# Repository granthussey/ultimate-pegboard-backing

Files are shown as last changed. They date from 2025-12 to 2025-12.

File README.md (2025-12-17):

# Pegboard Backing System

Modular pegboard backings with smart beveling and configurable peg placement patterns. Designed for 1" x 1" pegboards with 1/4" holes.

## Quick Start

**Just want to print?** Grab an STL from the `stl/` folder:
- `backing_2x1.stl` - 2-wide, 1-tall, corner pegs only
- `backing_2x2_grid.stl` - 2x2 with full grid of pegs
- `backing_3x2_maxhook.stl` - 3x2 with maximum hooks for heavy items

**Want to customize?** Use the OpenSCAD files in `scad/` with `pegboard_library.scad`.

## Print Settings

- **Layer height:** 0.2mm recommended
- **Infill:** 20-30% for light items, 50%+ for heavy items
- **Supports:** None needed
- **Orientation:** Print flat (pegs pointing up)

## Backing Variants

| Suffix | Pattern | Best For |
|---|---|---|
| (none) | Corner pegs only | Light items |
| `_grid` | All pegs, corner hooks | Medium items |
| `_maxhook` | All pegs, all back hooks | Heavy items |
| `_support` | Corners + middle hook | Medium-light items |
| `_lite` | Corner pegs, center cutout | Light items, fast printing |
| `_grid_lite` | Grid + center cutout | Medium items, fast printing |
| `_maxhook_lite` | Maxhook + center cutout | Heavy items, fast printing |
| `_support_lite` | Support + center cutout | Medium-light items, fast printing |

### Lite Variants
The `_lite` variants have a rectangular cutout in the center, reducing material by ~40-50% and printing ~40-50% faster. A 6mm frame around the edges preserves structural integrity at the peg locations.

**Important:** For lite variants, pegs are only placed on the outer frame where material exists. Grid and maxhook patterns become perimeter patterns (no interior pegs since there's no backing material to support them).

Available lite versions:
- `backing_*_lite.stl` - Corner pegs only, lightweight
- `backing_*_grid_lite.stl` - Perimeter pegs, corner hooks, lightweight
- `backing_*_maxhook_lite.stl` - Perimeter pegs, all back hooks, lightweight
- `backing_*_support_lite.stl` - Corner pegs + middle hook, lightweight (3x1, 3x2 only)

### Grid vs Maxhook Equivalence

For **1-column backings** (1x2, 1x3), the `_grid` and `_maxhook` variants are **identical**. This is because the back row only has 2 peg positions (both corners), so "all back hooks" and "corner hooks" produce the same result. Use `_grid` for these sizes.

## Dimensions

| Grid | Size (mm) | Size (inches) |
|---|---|---|
| 1x1 | 31.75 x 31.75 | 1.25" x 1.25" |
| 2x1 | 57.15 x 31.75 | 2.25" x 1.25" |
| 3x1 | 82.55 x 31.75 | 3.25" x 1.25" |
| 2x2 | 57.15 x 57.15 | 2.25" x 2.25" |
| 3x2 | 82.55 x 57.15 | 3.25" x 2.25" |

## Customization

Create your own backing sizes using OpenSCAD:

```openscad
include <pegboard_library.scad>

$fn = 64;
cols = 3;  // Width in tiles
rows = 2;  // Height in tiles

// Choose your pattern:
pegboard_backing(cols, rows, "corners");           // Standard
pegboard_backing(cols, rows, "grid");              // Maxhook (all hooks)
pegboard_backing(cols, rows, "grid_corner_hooks"); // Grid (corner hooks)
pegboard_backing(cols, rows, "perimeter");         // Edge pegs

// Or use lite variants for faster printing:
pegboard_backing_lite(cols, rows, "corners");           // Standard lite
pegboard_backing_lite(cols, rows, "grid");              // Maxhook lite
pegboard_backing_lite(cols, rows, "grid_corner_hooks"); // Grid lite
```

### Adding Custom Geometry

```openscad
include <pegboard_library.scad>

$fn = 64;
cols = 2;
rows = 1;

pegboard_backing(cols, rows, "corners");

// Add your custom geometry on top
w = backing_width(cols);
h = backing_height(rows);

translate([w/2, h/2, BACKING_THICKNESS])
    your_custom_holder();
```

### Utility Functions

```openscad
backing_width(cols)    // Total width accounting for shared pegs
backing_height(rows)   // Total height accounting for shared pegs
peg_x(i, cols)         // X position for peg at column i
peg_y(j, rows)         // Y position for peg at row j
```

## Technical Details

### Core Parameters

| Parameter | Value | Description |
|---|---|---|
| `TILE_SIZE` | 31.75mm (1.25") | Single tile dimension |
| `PEG_DIAMETER` | 5.5mm | Peg diameter |
| `PEG_SPACING` | 25.4mm (1") | Pegboard hole spacing |
| `BACKING_THICKNESS` | 4mm | Backing plate thickness |

### Why PEG_SPACING = 25.4mm

Standard pegboards have holes spaced exactly **1 inch (25.4mm)** apart, center-to-center. Multi-tile backings use this spacing:

```
width = TILE_SIZE + (cols - 1) × PEG_SPACING
      = 31.75 + (cols - 1) × 25.4
```

This is why a 2x1 backing is 57.15mm wide, not 63.5mm.

### Interference-Fit Peg Spacing

The pegs are intentionally placed at `EDGE_OFFSET` (2.75mm) from the plate edges, **not** at the exact pegboard hole spacing. This creates a critical **interference fit**:

| Backing | Peg Spacing | Hole Spacing | Difference |
|---|---|---|---|
| 1x1 | 26.25mm | 25.4mm | +0.85mm |

**Why this matters:** The 0.85mm spread creates outward pressure when the pegs are inserted into the pegboard holes. This pressure makes the backing grip the holes securely instead of falling out.

If pegs were placed at exactly 25.4mm spacing, they would drop straight into the holes with no grip - the backing would be "too loose" and fall out easily.

**Technical details:**
- Corner pegs: Always at `EDGE_OFFSET` from plate edges (interference fit)
- Edge pegs (perimeter/grid): Corners use interference fit, intermediate positions use `peg_x()`/`peg_y()` for proper alignment
- Interior pegs (grid patterns): Use exact `peg_x()`/`peg_y()` spacing

## File Organization

```
pegboard_backing/
├── README.md              # This file
├── pegboard_library.scad  # Core library for customization
├── stl/                   # Ready-to-print STL files
│   ├── backing_*.stl
│   └── ...
└── scad/                  # OpenSCAD source files
    ├── backing_*.scad
    └── ...
```

## License

This work is licensed under [CC BY 4.0](https://creativecommons.org/licenses/by/4.0/). You are free to share and adapt, with attribution.

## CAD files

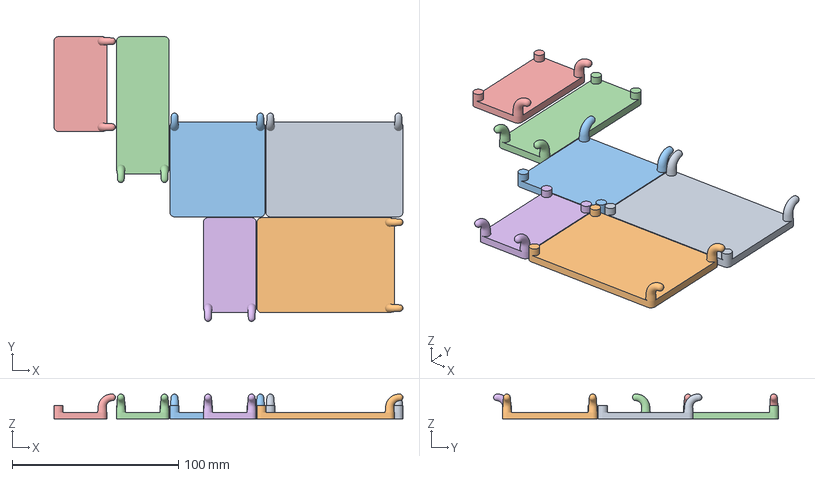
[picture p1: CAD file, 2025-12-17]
swatch.3mf
209.9 x 171.3 x 15.0 mm
backing_3x2_base
backing_2x3_base
backing_2x2_base
backing_1x3_base
backing_2x1_base
backing_1x2_base

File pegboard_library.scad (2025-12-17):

// ============================================================================
// PEGBOARD LIBRARY - Tiled Backing System with Smart Beveling
// ============================================================================
// For 1" x 1" pegboards with 1/4" holes
// Supports 1D and 2D tiling with adaptive peg placement
// ============================================================================
//
// QUICK REFERENCE - Peg Patterns for pegboard_backing(cols, rows, pattern):
//   "corners"          - 4 pegs at corners only (default)
//   "perimeter"        - Pegs around all edges at tile boundaries
//   "grid"             - All pegs, back row ALL hooks (_maxhook)
//   "grid_corner_hooks"- All pegs, only corner hooks (_grid)
//   "none"             - No pegs (backing plate only)
//
// IMPORTANT: Multi-tile backings share pegs at boundaries!
//   1x1 = 31.75mm, 2x1 = 57.15mm, 3x1 = 82.55mm
//
// See README.md for full documentation
// ============================================================================

// === Base Parameters (from UNIVERSAL_BASE_DESIGN.scad - DO NOT CHANGE) ===
TILE_SIZE = 31.75;          // Single tile dimension (mm)
PEG_DIAMETER = 5.5;         // Peg diameter (mm)
BACKING_THICKNESS = 4;      // Backing plate thickness (mm)

// === Peg Spacing (CRITICAL for multi-tile backings) ===
// Standard pegboard hole spacing is exactly 1 inch (25.4mm) center-to-center
PEG_SPACING = 25.4;  // 1 inch - actual pegboard hole spacing

// === Peg Parameters ===
FRONT_PEG_HEIGHT = 4;       // Plain cylinders (front/top edge)
BACK_PEG_HEIGHT = 3;        // Hook pegs (back/bottom edge)
BEND_RADIUS = 6;            // Hook curve radius
PEG_TO_END = 6;             // Hook extension length
TAPER_END = 4;              // Diameter at hook tip
EDGE_OFFSET = PEG_DIAMETER / 2;  // Distance from edge to peg center (2.75mm)
BEVEL_RADIUS = EDGE_OFFSET;      // Corner rounding radius (2.75mm)

// === Resolution ===
$fn = 32;
CURVE_SEGMENTS = 16;

// ============================================================================
// UTILITY FUNCTIONS - Correct tiled dimensions
// ============================================================================

// Returns the total width of a tiled backing (accounts for shared pegs)
function backing_width(cols) = TILE_SIZE + (cols - 1) * PEG_SPACING;

// Returns the total height of a tiled backing (accounts for shared pegs)
function backing_height(rows) = TILE_SIZE + (rows - 1) * PEG_SPACING;

// Returns the center X position for centering objects
function backing_center_x(cols) = backing_width(cols) / 2;

// Returns the center Y position for centering objects
function backing_center_y(rows) = backing_height(rows) / 2;

// Returns peg X position for column index i (0 to cols)
function peg_x(i, cols) = EDGE_OFFSET + i * PEG_SPACING;

// Returns peg Y position for row index j (0 to rows)
function peg_y(j, rows) = EDGE_OFFSET + j * PEG_SPACING;

// ============================================================================
// CORE MODULES - Backing Plates
// ============================================================================

// Creates a backing plate with correct tiled dimensions and selective corner rounding
module tiled_backing_plate(cols, rows, bevel_all = true) {
    w = backing_width(cols);
    h = backing_height(rows);
    z = BACKING_THICKNESS;
    r = bevel_all ? BEVEL_RADIUS : 0.01;

    hull() {
        // Four corners
        translate([r, r, 0])
            cylinder(h = z, r = r);
        translate([w - r, r, 0])
            cylinder(h = z, r = r);
        translate([r, h - r, 0])
            cylinder(h = z, r = r);
        translate([w - r, h - r, 0])
            cylinder(h = z, r = r);
    }
}

// ============================================================================
// CORE MODULES - Pegs
// ============================================================================

// Plain cylindrical peg (for front edge)
module plain_peg(height = FRONT_PEG_HEIGHT) {
    cylinder(h = height, d = PEG_DIAMETER);
}

// Tapered peg with hook (for back edge)
module tapered_peg_and_hook(peg_height = BACK_PEG_HEIGHT) {
    total_segments = CURVE_SEGMENTS + 8;

    // Tapered peg (vertical portion)
    for (i = [0 : 7]) {
        z1 = peg_height * i / 8;
        z2 = peg_height * (i + 1) / 8;
        d1 = PEG_DIAMETER - (PEG_DIAMETER - TAPER_END) * i / total_segments;
        d2 = PEG_DIAMETER - (PEG_DIAMETER - TAPER_END) * (i + 1) / total_segments;

        hull() {
            translate([0, 0, z1]) cylinder(h = 0.01, d = d1);
            translate([0, 0, z2]) cylinder(h = 0.01, d = d2);
        }
    }

    // Tapered curve (hook portion)
    for (i = [0 : CURVE_SEGMENTS - 1]) {
        angle1 = 90 * i / CURVE_SEGMENTS;
        angle2 = 90 * (i + 1) / CURVE_SEGMENTS;
        seg_index1 = 8 + i;
        seg_index2 = 8 + i + 1;
        d1 = PEG_DIAMETER - (PEG_DIAMETER - TAPER_END) * seg_index1 / total_segments;
        d2 = PEG_DIAMETER - (PEG_DIAMETER - TAPER_END) * seg_index2 / total_segments;

        translate([0, 0, peg_height])
            rotate([90, 0, -90])
                translate([-BEND_RADIUS, 0, 0])
                    hull() {
                        rotate([0, 0, angle1])
                            translate([BEND_RADIUS, 0, 0])
                                sphere(d = d1);
                        rotate([0, 0, angle2])
                            translate([BEND_RADIUS, 0, 0])
                                sphere(d = d2);
                    }
    }
}

// ============================================================================
// PEG PLACEMENT PATTERNS (using correct PEG_SPACING)
// ============================================================================

// Places pegs at all four corners of the tiled assembly
// Front corners get plain pegs, back corners get hooks
// Uses interference-fit spacing (EDGE_OFFSET from plate edges) for secure grip
module place_pegs_corners(cols, rows) {
    w = backing_width(cols);
    h = backing_height(rows);

    // Corner positions using interference-fit spacing
    // Pegs at EDGE_OFFSET from plate edges creates ~0.85mm spread vs exact hole spacing
    // This spread creates outward pressure that grips the pegboard holes
    x_left = EDGE_OFFSET;
    x_right = w - EDGE_OFFSET;
    y_front = EDGE_OFFSET;
    y_back = h - EDGE_OFFSET;

    // Front corners (plain pegs)
    translate([x_left, y_front, BACKING_THICKNESS])
        plain_peg();
    translate([x_right, y_front, BACKING_THICKNESS])
        plain_peg();

    // Back corners (hook pegs)
    translate([x_left, y_back, BACKING_THICKNESS])
        tapered_peg_and_hook();
    translate([x_right, y_back, BACKING_THICKNESS])
        tapered_peg_and_hook();
}

// Places pegs around the perimeter at each peg position
// Front edge: plain pegs, Back edge: hook pegs
// Uses interference-fit spacing at outer edges for secure grip
module place_pegs_perimeter(cols, rows) {
    w = backing_width(cols);
    h = backing_height(rows);

    // Outer edge positions using interference-fit spacing
    x_left = EDGE_OFFSET;
    x_right = w - EDGE_OFFSET;
    y_front = EDGE_OFFSET;
    y_back = h - EDGE_OFFSET;

    // Front edge (plain pegs)
    // Corner pegs at interference-fit positions, intermediate at peg_x()
    for (i = [0 : cols]) {
        x = (i == 0) ? x_left : (i == cols) ? x_right : peg_x(i, cols);
        translate([x, y_front, BACKING_THICKNESS])
            plain_peg();
    }

    // Back edge (hook pegs)
    // Corner pegs at interference-fit positions, intermediate at peg_x()
    for (i = [0 : cols]) {
        x = (i == 0) ? x_left : (i == cols) ? x_right : peg_x(i, cols);
        translate([x, y_back, BACKING_THICKNESS])
            tapered_peg_and_hook();
    }

    // Left edge (intermediate rows only)
    for (j = [1 : rows - 1]) {
        y = peg_y(j, rows);
        translate([x_left, y, BACKING_THICKNESS])
            plain_peg();
    }

    // Right edge (intermediate rows only)
    for (j = [1 : rows - 1]) {
        y = peg_y(j, rows);
        translate([x_right, y, BACKING_THICKNESS])
            plain_peg();
    }
}

// Places pegs in a grid pattern at each position
// Back row gets hooks, all others get plain pegs
// Uses interference-fit spacing at outer edges for secure grip
module place_pegs_grid(cols, rows) {
    w = backing_width(cols);
    h = backing_height(rows);

    // Outer edge positions using interference-fit spacing
    x_left = EDGE_OFFSET;
    x_right = w - EDGE_OFFSET;
    y_front = EDGE_OFFSET;
    y_back = h - EDGE_OFFSET;

    for (i = [0 : cols]) {
        for (j = [0 : rows]) {
            // Edge pegs at interference-fit positions, interior at peg_x()/peg_y()
            x = (i == 0) ? x_left : (i == cols) ? x_right : peg_x(i, cols);
            y = (j == 0) ? y_front : (j == rows) ? y_back : peg_y(j, rows);
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

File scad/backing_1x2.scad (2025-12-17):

// === Pegboard Backing Test: 1x2 Grid ===
// 1 column, 2 rows
// Total size: 31.75mm wide x 63.5mm tall

include <../pegboard_library.scad>

$fn = 64;

// Grid configuration
cols = 1;
rows = 2;

// Create backing with corner pegs
pegboard_backing(cols, rows, "corners");

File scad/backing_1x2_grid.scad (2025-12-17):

// === Pegboard Backing Grid: 1x2 ===
// 1 column, 2 rows - ALL pegs at every tile intersection, hooks only at corners

include <../pegboard_library.scad>

$fn = 64;

cols = 1;
rows = 2;

pegboard_backing(cols, rows, "grid_corner_hooks");

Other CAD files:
scad/backing_1x2_grid_lite.scad
scad/backing_1x2_lite.scad
scad/backing_1x2_maxhook.scad
scad/backing_1x3.scad
scad/backing_1x3_grid.scad
scad/backing_1x3_grid_lite.scad
scad/backing_1x3_lite.scad
scad/backing_1x3_maxhook.scad
scad/backing_2x1.scad
scad/backing_2x1_grid.scad
scad/backing_2x1_grid_lite.scad
scad/backing_2x1_lite.scad
scad/backing_2x1_maxhook.scad
scad/backing_2x1_maxhook_lite.scad
scad/backing_2x2.scad
scad/backing_2x2_grid.scad
scad/backing_2x2_grid_lite.scad
scad/backing_2x2_lite.scad
scad/backing_2x2_maxhook.scad
scad/backing_2x2_maxhook_lite.scad
scad/backing_2x3.scad
scad/backing_2x3_grid.scad
scad/backing_2x3_grid_lite.scad
scad/backing_2x3_lite.scad
scad/backing_2x3_maxhook.scad
scad/backing_2x3_maxhook_lite.scad
scad/backing_3x1.scad
scad/backing_3x1_grid.scad
scad/backing_3x1_grid_lite.scad
scad/backing_3x1_lite.scad
scad/backing_3x1_maxhook.scad
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

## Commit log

2025-12-17 Fixed issues
    [backing_1x2_grid_lite.scad, backing_1x2_lite.scad, backing_1x3_grid_lite.scad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]
2025-12-17 Fix gripping
    [pegboard_library.scad]
2025-12-17 made swatches for bambu
    [swatch.3mf]
